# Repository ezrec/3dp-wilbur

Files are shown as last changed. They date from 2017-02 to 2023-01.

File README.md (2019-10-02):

# Wilbur - a Core-XY arm printer

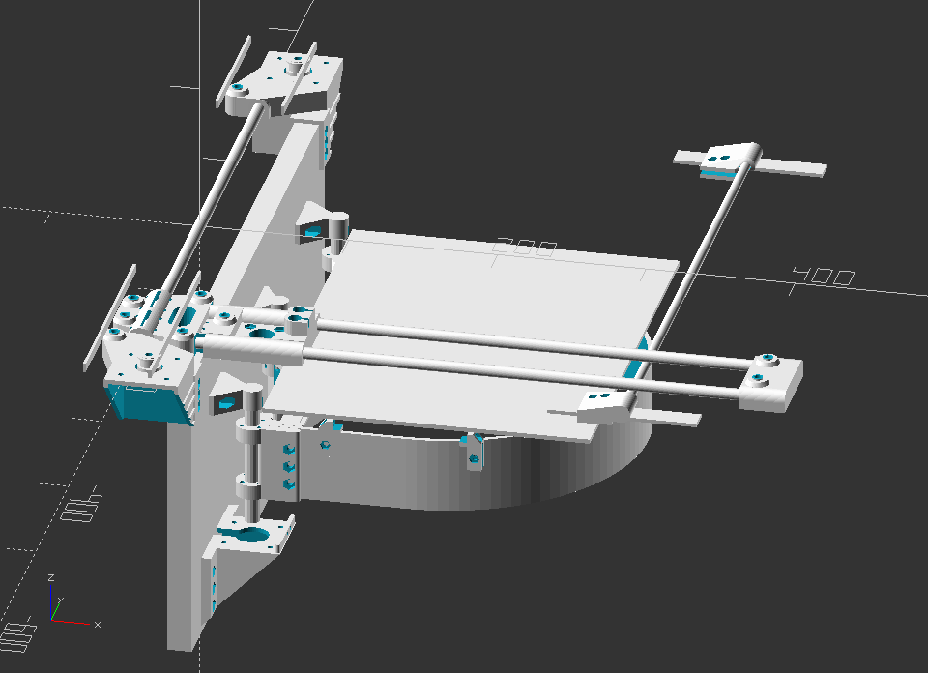
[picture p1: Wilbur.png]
Image of Wilbur


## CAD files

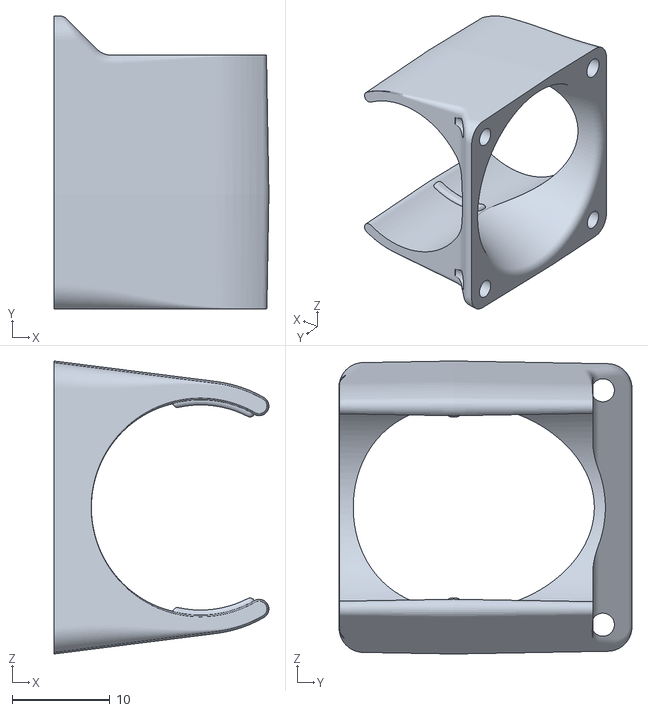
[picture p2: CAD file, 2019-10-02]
E3D/V6.6_Duct.stl
22.0 x 30.0 x 30.0

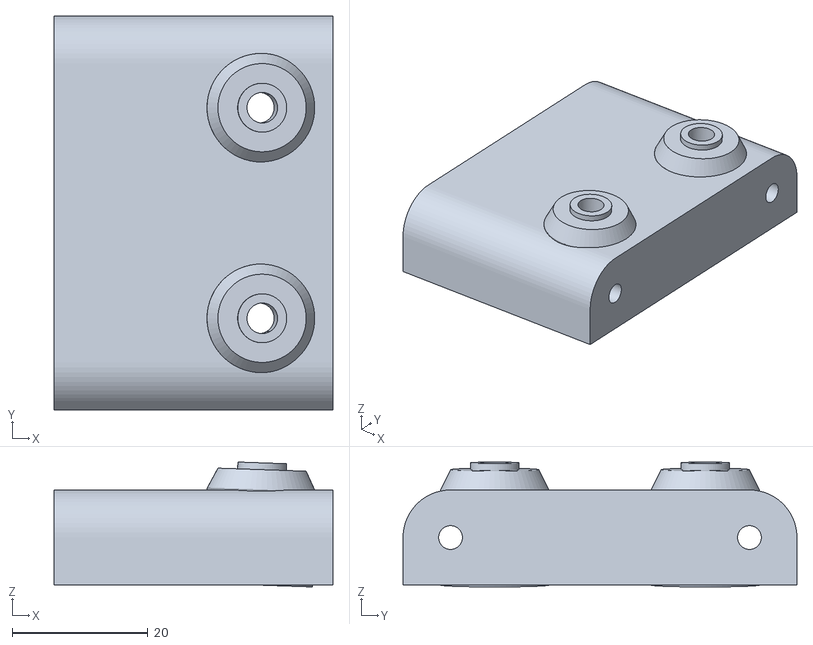
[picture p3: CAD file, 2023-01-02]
stl/wilbur_x_cap.stl
41.0 x 58.0 x 18.4

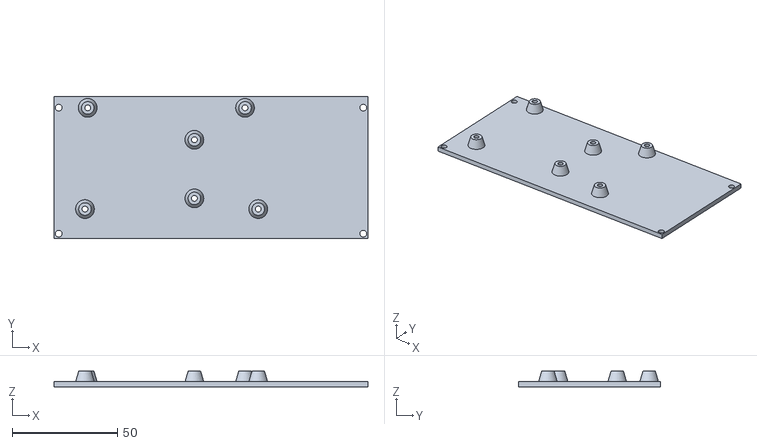
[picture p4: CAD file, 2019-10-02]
stl/wilbur_control_box_base.stl
149.5 x 67.5 x 7.50

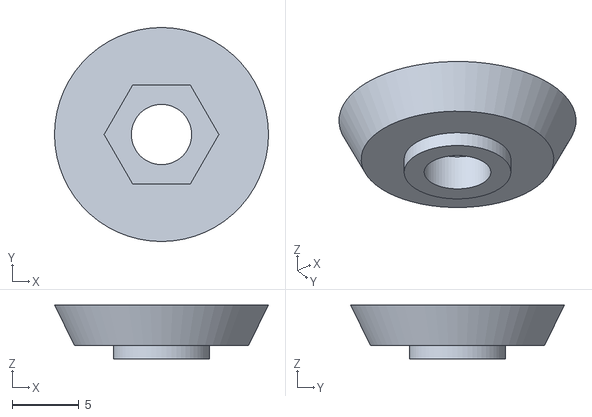
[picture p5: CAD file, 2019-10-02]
stl/wilbur_bearing_cap.stl
16.0 x 16.0 x 4.01

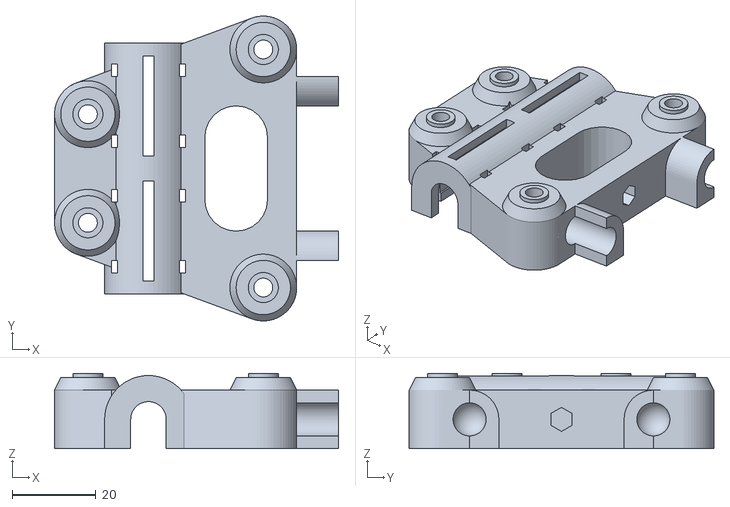
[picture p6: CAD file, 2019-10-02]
stl/wilbur_block.stl
68.0 x 73.0 x 18.0

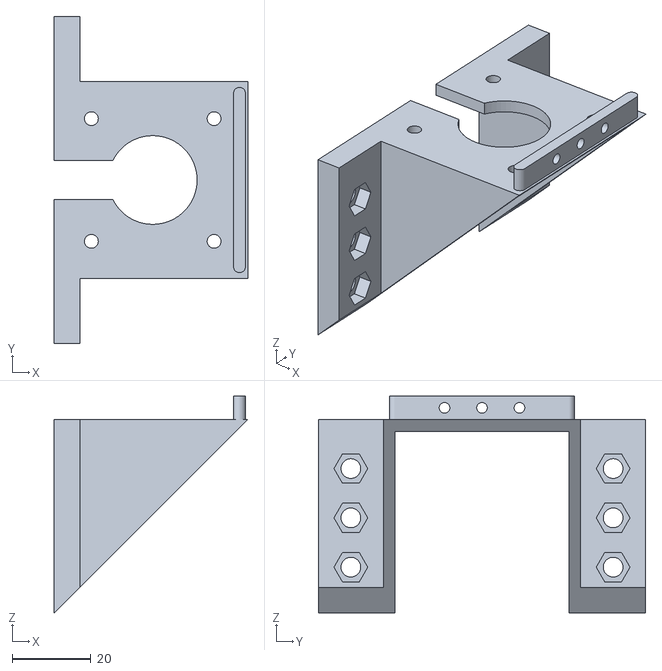
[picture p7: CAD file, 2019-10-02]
stl/wilbur_z_motor.stl
49.1 x 83.0 x 55.0

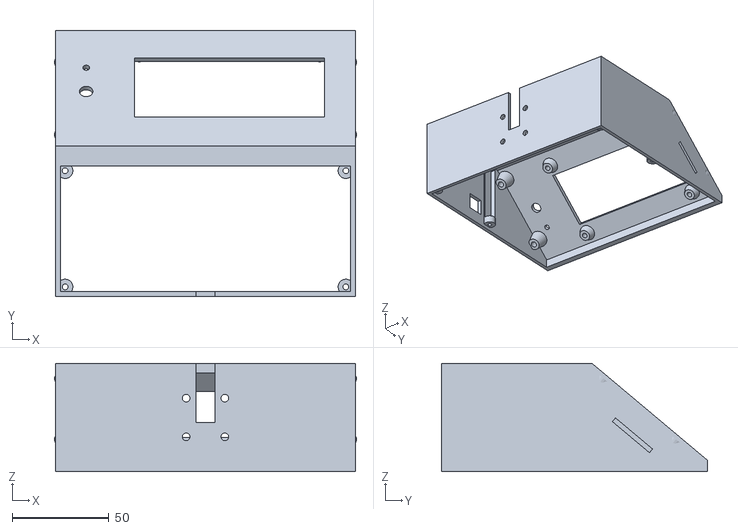
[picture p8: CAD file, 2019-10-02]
stl/wilbur_control_box.stl
156.0 x 137.5 x 56.0

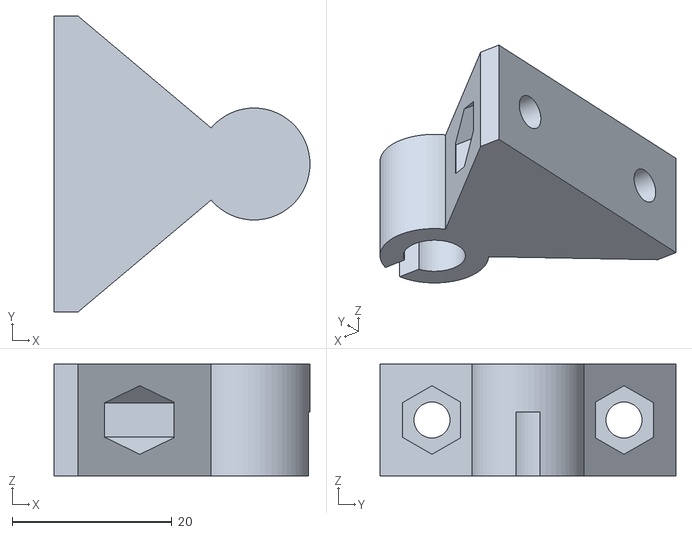
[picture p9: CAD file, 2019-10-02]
stl/wilbur_z_cap.stl
32.0 x 37.0 x 14.0

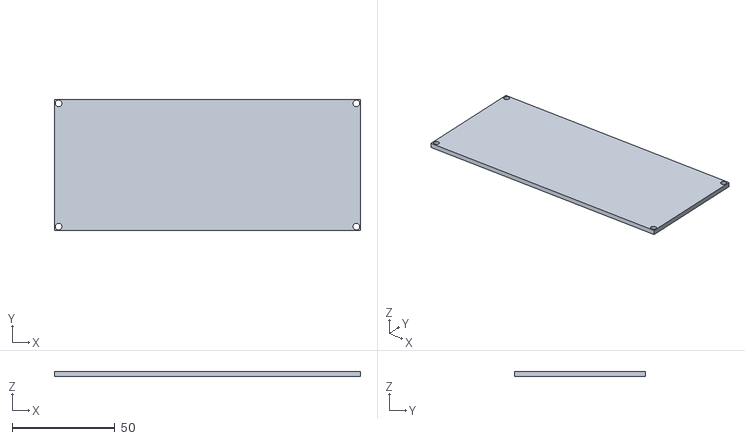
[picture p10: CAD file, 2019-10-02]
stl/wilbur_control_box_lid.stl
149.0 x 64.0 x 2.50

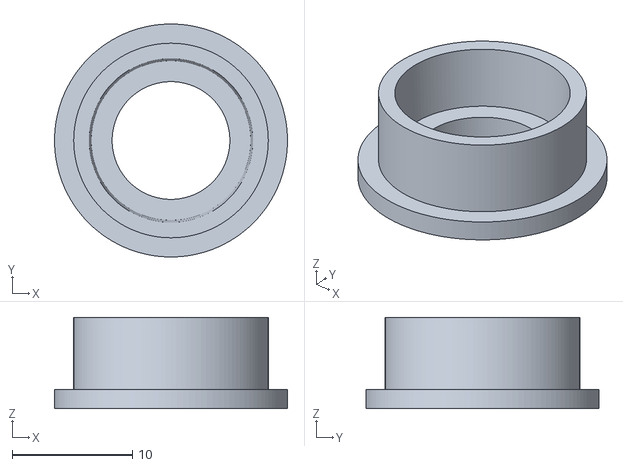
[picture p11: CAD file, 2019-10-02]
stl/wilbur_bearing_sleeve.stl
19.4 x 19.4 x 7.60

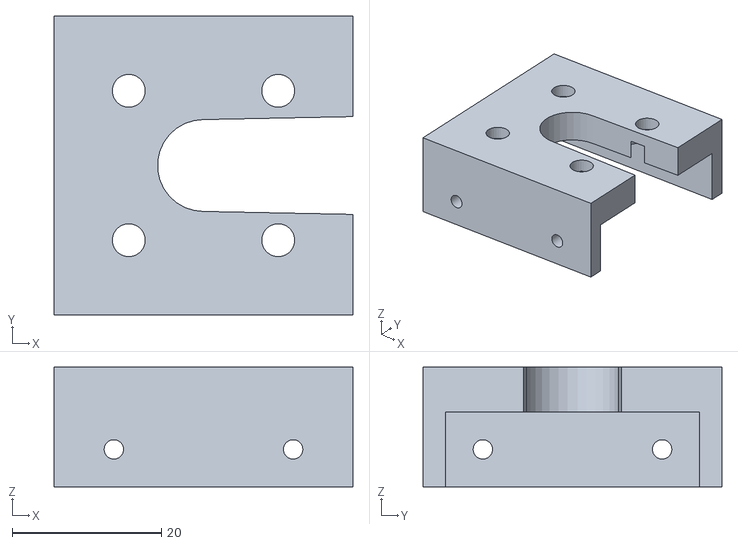
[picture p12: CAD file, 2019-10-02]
stl/wilbur_hotend_e3d_v6.stl
40.0 x 40.0 x 16.0

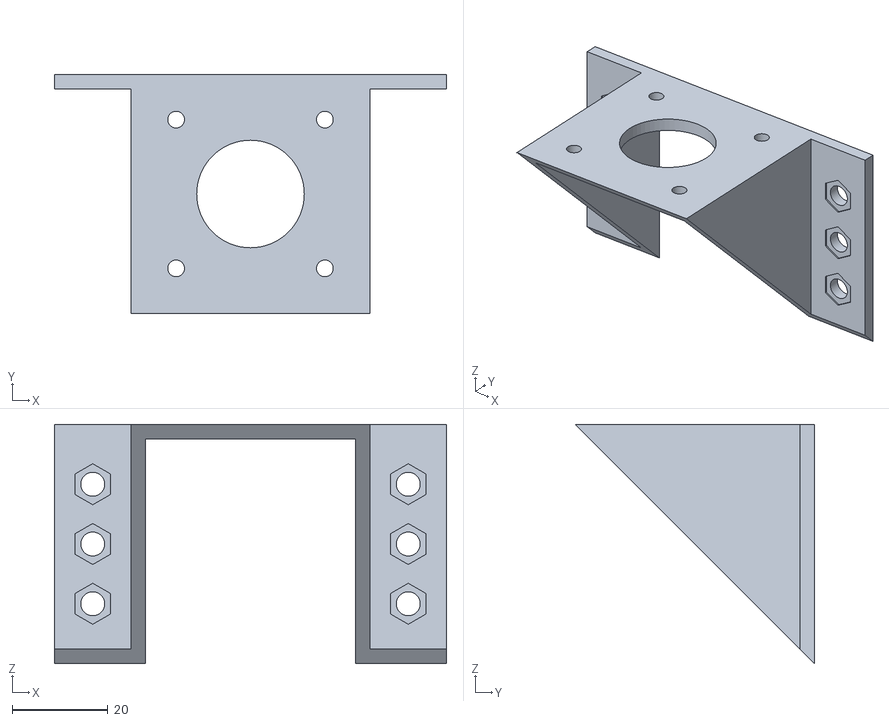
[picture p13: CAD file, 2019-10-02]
stl/wilbur_z_mount.stl
82.0 x 50.0 x 50.0

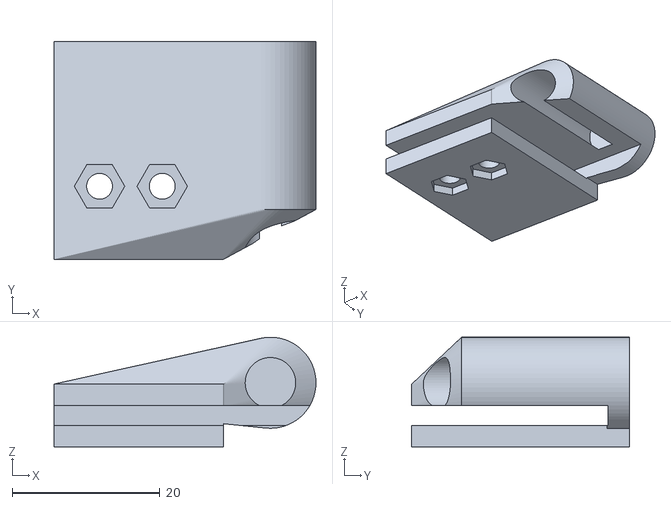
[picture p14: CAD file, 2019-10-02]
stl/wilbur_y_rail_min.stl
35.5 x 29.5 x 14.8

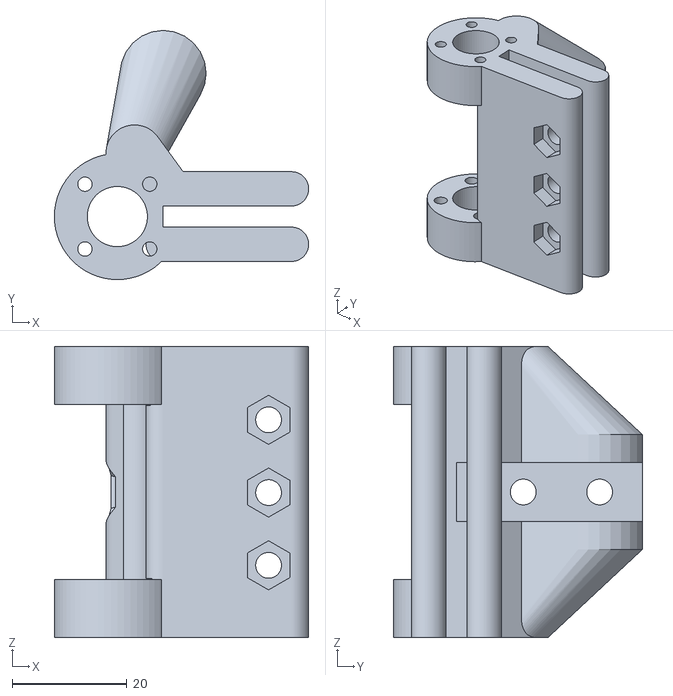
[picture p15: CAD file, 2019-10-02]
stl/wilbur_z_edge.stl
44.4 x 43.5 x 50.8

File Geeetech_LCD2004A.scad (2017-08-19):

bottom_plate=[150, 55, 1.6];

top_plate = [98.2, 60, 1.6];

fn=30;

function geeetech_lcd2004a_size() = [150, 63, 10];

module plate_drills(size=[10,20, 30], offset=2, drill=3)
{
    translate([offset, offset]) circle(d=drill, $fn=fn);
    translate([size[0]-offset, offset]) circle(d=drill, $fn=fn);
    translate([offset, size[1]-offset]) circle(d=drill, $fn=fn);
    translate([size[0]-offset, size[1]-offset]) circle(d=drill, $fn=fn);
}

module plate_mounts(size=[10,20, 30], offset=2, drill=3, height=10, wall=2)
{
    translate([0, 0, size[2]]) difference()
    {
        union()
        {
            translate([offset, offset])
                cylinder(d1=drill+wall*2, d2=drill+wall*4, h=height, $fn=fn);
            translate([size[0]-offset, offset])
                cylinder(d1=drill+wall*2, d2=drill+wall*4, h=height, $fn=fn);
            translate([offset, size[1]-offset])
                cylinder(d1=drill+wall*2, d2=drill+wall*4, h=height, $fn=fn);
            translate([size[0]-offset, size[1]-offset])
                cylinder(d1=drill+wall*2, d2=drill+wall*4, h=height, $fn=fn);
        }
        translate([0, 0, -0.1]) linear_extrude(height=height+0.2) plate_drills(size, offset, drill);
    }
}

module plate(size=[10,20, 30], offset=2, drill=3)
{
    linear_extrude(height=size[2]) difference()
    {
        square([size[0], size[1]]);
        plate_drills(size, offset, drill);
    }
}

module geeetech_lcd2004a()
{
    translate([-bottom_plate[0]/2, 0, 0])
    {
        plate(bottom_plate, offset=3, drill=4);
        // SD card
        translate([-10, 9, -2.4])
            cube([35, 25, 2.5]); 
        translate([0, 0, bottom_plate[2]]) {
            translate([bottom_plate[0]-16.5, 5.5, 0]) {
                cube([6.3, 6.3, 3.5]);
                translate([6.3/2, 6.3/2, 0]) {
                    cylinder(d=3.5, h=14.5, $fn=fn);
                    translate([0, 16, 0]) {
                        translate([0, 0, 6.8/2]) cube([12, 12, 6.8], center=true);
                        cylinder(d=7, h=26.5, $fn=fn);
                    }
                }
            }
        }
        
        // LCD2004A
        translate([13.5, bottom_plate[1] - top_plate[1] - 3, bottom_plate[2]+3]) {
            plate(top_plate, offset=2.5, drill=3.5);
            translate([0, 10, top_plate[2]])
                cube([top_plate[0], 40, 9.5]);
        }
        
    }
}

module geeetech_lcd2004a_mounts(wall=4)
{
    translate([-bottom_plate[0]/2, 0, 0])
    {
        plate_mounts(bottom_plate, offset=3, drill=4, height=3+top_plate[2]+9.5-wall);
        translate([13.5, bottom_plate[1] - top_plate[1] - 3, bottom_plate[2]+3])
        {
            plate_mounts(top_plate, offset=2.5, drill=3.5, height=9.5-wall);
        }
    }
}

module geeetech_lcd2004a_holder(angle=40, width=80, height=100, wall=3)
{
    old_size=geeetech_lcd2004a_size();
    size = [old_size[0], old_size[1] + 10, old_size[2]];
    h = height - sin(angle)*(size[1]+wall*2);

    translate([0, 0, h])
    {
        // Polyline
        difference()
        {
            translate([-size[0]/2-wall, 0, 0]) rotate([0, 0, 90]) rotate([90, 0, 0]) difference()
            {
                 linear_extrude(height=size[0]+wall*2) polygon([[0, 0], [0, -h], [width, -h], [width, sin(angle)*(size[1]+wall*2)], [cos(angle)*(size[1]+wall*2), sin(angle)*(size[1]+wall*2)]]);
                 translate([0, -0.01, wall]) linear_extrude(height=size[0]) polygon([[wall+cos(angle)*wall, 0], [wall+cos(angle)*wall, -h], [width-wall, -h], [width-wall,sin(angle)*size[1]], [cos(angle)*size[1]+wall+cos(angle)*wall, sin(angle)*size[1]]]);
            }

            translate([0, wall+wall*cos(angle)+size[2]+size[2]*cos(angle) - 0.5, 0]) rotate([angle, 0, 0])
                geeetech_lcd2004a();
        }

        translate([0, wall+wall*cos(angle)+size[2]+size[2]*cos(angle) - 0.5, 0]) rotate([angle, 0, 0])
        {
            geeetech_lcd2004a_mounts();
            % geeetech_lcd2004a();
        }
    }
}


geeetech_lcd2004a_holder(wall=3);

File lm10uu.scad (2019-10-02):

mm = 1.0;
in = 25.4;

fn = 120;

module bearing_surface(od = 10 * mm, id = 5 * mm, surfaces = 4)
{
    difference()
    {
        union()
        {
            // Outer wall
            difference()
            {
                circle(d = od, $fn=fn);
                circle(d = od - (od - id) * 1 / 3, $fn=fn);
            }

            // Surfaces
            for (a = [0:surfaces-1])
            {
                a1 = a * 360/surfaces;
                a2 = a1 + 360/surfaces/2;
                polygon([[0,0], [od/2 * cos(a1), od/2 * sin(a1)], [od/2 * cos(a2), od/2 * sin(a2)]]);
            }
        }
        
        circle(d = id, $fn = fn);
    }
}

module lm_bearing(h=10, id=5, od=10, surfaces=6)
{
    linear_extrude(height=h/2, twist = h)
    {
        bearing_surface(od=od, id=id * 0.975, surfaces = surfaces);
    }
    mirror([0, 0, 1]) linear_extrude(height=h/2, twist = h)
    {
        bearing_surface(od=od, id=id * 0.975, surfaces = surfaces);
    }
}

module lm8uu()
{
    lm_bearing(h=24*mm, od=15*mm, id=8*mm, surfaces=13);
}

module lm10uu()
{
    lm_bearing(h=29*mm, od=19*mm, id=10*mm, surfaces=15);
}

lm8uu();

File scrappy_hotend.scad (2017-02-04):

//
// Copyright (C) 2017, Jason S. McMullan <jason.mcmullan@gmail.com>
// All rights reserved.
//
// Licensed under the MIT License:
//
// Permission is hereby granted, free of charge, to any person obtaining
// a copy of this software and associated documentation files (the "Software"),
// to deal in the Software without restriction, including without limitation
// the rights to use, copy, modify, merge, publish, distribute, sublicense,
// and/or sell copies of the Software, and to permit persons to whom the
// Software is furnished to do so, subject to the following conditions:
//
// The above copyright notice and this permission notice shall be included
// in all copies or substantial portions of the Software.
//
// THE SOFTWARE IS PROVIDED "AS IS", WITHOUT WARRANTY OF ANY KIND, EXPRESS OR
// IMPLIED, INCLUDING BUT NOT LIMITED TO THE WARRANTIES OF MERCHANTABILITY,
// FITNESS FOR A PARTICULAR PURPOSE AND NONINFRINGEMENT. IN NO EVENT SHALL THE
// AUTHORS OR COPYRIGHT HOLDERS BE LIABLE FOR ANY CLAIM, DAMAGES OR OTHER
// LIABILITY, WHETHER IN AN ACTION OF CONTRACT, TORT OR OTHERWISE, ARISING
// FROM, OUT OF OR IN CONNECTION WITH THE SOFTWARE OR THE USE OR OTHER
// DEALINGS IN THE SOFTWARE.
//
// All units are in mm

use <Geeetech/jhead_peek.scad>
use <mini_height_sensor.scad>

geeetech_peek_clamp_diameter = 12;
geeetech_peek_clamp_height = 4.5;
geeetech_peek_bulk_diameter = 16;
geeetech_peek_bulk_length = 29;

geeetech_peek_nozzle_height = 16;

m4_nut_flat=7;
m4_nut_height=3.5;

drill_tolerance = 0.25;

blower_fan_mounting_radius = 49.5/2;
blower_fan_width = 19.5;
blower_fan_mounting_post_height = 7;
blower_fan_mounting_post_diameter = 6.5;
blower_fan_radius = 41/2;
blower_fan_airflow_radius = 29/2;
blower_out_height = 30.5;

wall = 3;

fn=30;

module drill(d=3, h=1, tolerance=drill_tolerance)
{
    translate([0, 0, -0.1]) cylinder(d=d + tolerance*2, h=h+0.2, $fn =fn);
}

module blower_fan_of(cut=false)
{
    if (!cut)
    {
        // Mounting posts
        translate([0, blower_fan_width/2 - blower_fan_mounting_post_height, blower_fan_radius])
        for (x=[0:2]) rotate([0, 45+x*90, 0]) translate([blower_fan_mounting_radius, 0, 0])
                rotate([-90, 0, 0]) cylinder(d=blower_fan_mounting_post_diameter, h=blower_fan_mounting_post_height, $fn=fn);
        
        // Mounting
        translate([-blower_fan_radius, blower_fan_width/2-0.1, 0])
            cube([blower_fan_radius*2, wall, blower_fan_radius*2]);
    }
    else
    {
        translate([0, -blower_fan_width/2, blower_fan_radius]) {
            rotate([-90, 0, 0]) cylinder(r=blower_fan_radius, h=blower_fan_width, $fn=fn);
            translate([0, 0, blower_fan_radius - blower_out_height])
                cube([blower_fan_radius, blower_fan_width, blower_out_height]);
        }
        
        // Mounting drills
        translate([0, blower_fan_width/2 - blower_fan_mounting_post_height, blower_fan_radius])
        for (x=[0:2]) rotate([0, 45+x*90, 0]) translate([blower_fan_mounting_radius, 0, 0])
                rotate([-90, 0, 0]) drill(d=3, h=blower_fan_mounting_post_height+100, $fn=fn);
        
        // Airflow
        translate([0, -blower_fan_width/2, blower_fan_radius])
            rotate([-90, 0, 0]) cylinder(r=blower_fan_airflow_radius, h=blower_fan_width+100+0.2, $fn=fn);
    }
}
            
module hotend_geeetech_peek_of(cut=false)
{
    if (!cut)
    {
        translate([0, 0, geeetech_peek_clamp_height/2]) cube([40, 40, geeetech_peek_clamp_height], center=true);
        hull()
        {
        translate([-20, 20-1, 0]) cube([40, 1,geeetech_peek_clamp_height ]);
        // Mounting
        translate([-blower_fan_radius - geeetech_peek_bulk_diameter/2 - wall, 0, -blower_fan_radius*2])
            translate([-blower_fan_radius, blower_fan_width/2-0.1, 0])
            cube([blower_fan_radius*2, 1, blower_fan_radius*2]);
        }
        
        // Extra mounting bracket
        translate([20-0.01, -20, -10]) cube([wall, 40, 10+geeetech_peek_clamp_height]);        
    }
    else
    {
        // Cylinder drill
        translate([0, 0, -geeetech_peek_bulk_length])
            drill(d=geeetech_peek_bulk_diameter, h=geeetech_peek_bulk_length);
        
        // Mounting slot
        translate([0, 0, -0.01]) linear_extrude(height=geeetech_peek_clamp_height+0.02) hull()
        {
            circle(d=geeetech_peek_clamp_diameter + drill_tolerance*2+0.1);
            translate([0, -100, 0])
                circle(d=geeetech_peek_clamp_diameter + drill_tolerance*2+0.1);
        }
        
        // M4 mounting holes, 20mm apart
        for (r = [0:90:270]) rotate([0, 0, 45+r]) translate([20*sin(45), 0, 0]) {
            drill(h=geeetech_peek_clamp_height, d=4);
            translate([0, 0, -20])
                rotate([0, 0, 45+r]) cylinder(r=m4_nut_flat/sqrt(3)+drill_tolerance, h=m4_nut_height/2+20+0.1, $fn=6);
        }
        
        // Extra mounting bracket drills
        translate([20-0.01, 0, -5]) {
            translate([0, -10, 0]) rotate([0, 90, 0]) drill(h=5, d=3);
            translate([0, 10, 0]) rotate([0, 90, 0]) drill(h=5, d=3);
        }
    }
              
    translate([-blower_fan_radius - geeetech_peek_bulk_diameter/2 - wall, 0, -blower_fan_radius*2])
        blower_fan_of(cut);
 }

module scrappy_hotend_geeetech_peek()
{
    difference()
    {
        hotend_geeetech_peek_of(cut=false);
        hotend_geeetech_peek_of(cut=true);
    }
}

module scrappy_height_sensor_mount()
{
    height=geeetech_peek_bulk_length+geeetech_peek_nozzle_height-7;
    translate([20, 0, -height]) {
        difference()
        {
            translate([-5, -20+5, 0])
                cube([5, 30, height]);
            translate([-5, 0, (geeetech_peek_nozzle_height-6)/2])
                scale([8, 25, (height - geeetech_peek_nozzle_height+6)*3]) sphere(r=0.5, $fn=fn);
            # translate([-5.01, 0, height-5]) {
                translate([0, -10, 0]) rotate([0, 90, 0]) drill(h=5, d=3-drill_tolerance*2);
                translate([0, 10, 0]) rotate([0, 90, 0]) drill(h=5, d=3-drill_tolerance*2);
            }
        }
        
        translate([-5, 0, 0]) difference()
        {
            rotate([90, 0, 0]) rotate_extrude(angle=30, convexity=2) {
                difference() {
                    translate([0, -20+5]) square([5, 30]);
                    scale([8, 25]) circle(r=0.5, $fn=fn);
                }
            }
            translate([-5.1, -20.1+5, 0]) cube([10.2, 30.2, 5.1]);
            translate([-5.1, -20.1+5, -5.1]) cube([5.1, 30.2, 5.1]);
        }
        
        translate([0, 0, -5]) rotate([0, 0, 90]) mini_height_sensor_mount();
    }
}

scrappy_hotend_geeetech_peek();
scrappy_height_sensor_mount();
% geeetech_jhead_peek();
// vim: set shiftwidth=4 expandtab: //

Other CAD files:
stl/wilbur_fan_e3d_v6.stl
stl/wilbur_z_foot.stl
stl/wilbur_y_motor_min.stl
stl/wilbur_power_box.stl
wilbur.scad
E3D/chimera.scad
E3D/utility.scad
E3D/v6_block.scad
E3D/v6_break.scad
E3D/v6_lite.scad
E3D/v6_nozzle.scad
mini_height_sensor.scad
stl/wilbur_sensor_e3d_v6.stl
stl/wilbur_sled.stl
stl/wilbur_y_motor_max.stl
stl/wilbur_y_rail_max.stl
stl/wilbur_z_center.stl
wilbur_hotend_e3d.scad
wilbur_power_box.scad

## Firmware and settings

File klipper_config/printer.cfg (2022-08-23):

# Arduino aliases for atmega2560/1280 (Arduino mega) boards
[board_pins arduino-mega]
aliases:
    ar0=PE0, ar1=PE1, ar2=PE4, ar3=PE5, ar4=PG5,
    ar5=PE3, ar6=PH3, ar7=PH4, ar8=PH5, ar9=PH6,
    ar10=PB4, ar11=PB5, ar12=PB6, ar13=PB7, ar14=PJ1,
    ar15=PJ0, ar16=PH1, ar17=PH0, ar18=PD3, ar19=PD2,
    ar20=PD1, ar21=PD0, ar22=PA0, ar23=PA1, ar24=PA2,
    ar25=PA3, ar26=PA4, ar27=PA5, ar28=PA6, ar29=PA7,
    ar30=PC7, ar31=PC6, ar32=PC5, ar33=PC4, ar34=PC3,
    ar35=PC2, ar36=PC1, ar37=PC0, ar38=PD7, ar39=PG2,
    ar40=PG1, ar41=PG0, ar42=PL7, ar43=PL6, ar44=PL5,
    ar45=PL4, ar46=PL3, ar47=PL2, ar48=PL1, ar49=PL0,
    ar50=PB3, ar51=PB2, ar52=PB1, ar53=PB0, ar54=PF0,
    ar55=PF1, ar56=PF2, ar57=PF3, ar58=PF4, ar59=PF5,
    ar60=PF6, ar61=PF7, ar62=PK0, ar63=PK1, ar64=PK2,
    ar65=PK3, ar66=PK4, ar67=PK5, ar68=PK6, ar69=PK7,
    analog0=PF0, analog1=PF1, analog2=PF2, analog3=PF3, analog4=PF4,
    analog5=PF5, analog6=PF6, analog7=PF7, analog8=PK0, analog9=PK1,
    analog10=PK2, analog11=PK3, analog12=PK4, analog13=PK5, analog14=PK6,
    analog15=PK7,
    # Marlin adds these additional aliases
    ml70=PG4, ml71=PG3, ml72=PJ2, ml73=PJ3, ml74=PJ7,
    ml75=PJ4, ml76=PJ5, ml77=PJ6, ml78=PE2, ml79=PE6,
    ml80=PE7, ml81=PD4, ml82=PD5, ml83=PD6, ml84=PH2,
    ml85=PH7

# Filament sensor
[filament_switch_sensor ext1_out]
pause_on_runout: True
switch_pin: ^!ar15

# Enable pause/resume
[pause_resume]
recover_velocity: 50

# Virtual SD Card
#[virtual_sdcard]
#path=/opt/octoprint/wilbur/uploads/

[output_pin ATX_POWER]
pin: !ar2
value: 0

# ATX Power On
[gcode_macro M80]
gcode: SET_PIN PIN=ATX_POWER VALUE=1

# ATX Power off
[gcode_macro M81]
gcode: SET_PIN PIN=ATX_POWER VALUE=0

# Define a probe
[probe]
pin: ar18
x_offset: 0.0
y_offset: -32.0
z_offset = 3.4

[bed_tilt]
# Sigh. We have to manually compensate for the probe offset
points: 40,40
  150,40
  150,260
  40,260

[stepper_x]
step_pin: ar54
dir_pin: ar55
enable_pin: !ar38
rotation_distance: 32
microsteps: 16
position_endstop: -9
endstop_pin: ^!ar3
#endstop_pin: ^ar2
homing_speed: 50
position_min: -9
position_max: 180

[stepper_y]
step_pin: ar60
dir_pin: !ar61
enable_pin: !ar56
rotation_distance: 32
microsteps: 16
endstop_pin: ^!ar14
#endstop_pin: ^ar15
position_endstop: -12
position_min: -12
position_max: 270
homing_speed: 50

[stepper_z]
step_pin: ar46
dir_pin: ar48
enable_pin: !ar62
rotation_distance: 4
microsteps: 16
#endstop_pin: ^ar18
#endstop_pin: ^!ar19
endstop_pin: probe:z_virtual_endstop
position_min: -10
position_max: 250

[safe_z_home]
home_xy_position: 10,50
move_to_previous: True
z_hop: 5.0

[extruder]
step_pin: ar26
dir_pin: ar28
enable_pin: !ar24
rotation_distance: 32
microsteps: 16
nozzle_diameter: 0.600
filament_diameter: 1.750
heater_pin: ar10
sensor_type: ATC Semitec 104GT-2
sensor_pin: analog13
#control: pid
#pid_Kp: 22.2
#pid_Ki: 1.08
#pid_Kd: 114
min_temp: 0
max_temp: 230
pressure_advance: 0.1

[heater_bed]
heater_pin: ar8
sensor_type: NTC 100K beta 3950
sensor_pin: analog15
#control: watermark
min_temp: 0
max_temp: 130

[fan]
pin: ar9

[mcu]
serial: /dev/ttyACM0
baud: 230400

[printer]
kinematics: corexy
max_velocity: 300
max_accel: 3000
max_z_velocity: 5
max_z_accel: 100

# Common EXP1 / EXP2 (display) pins
[board_pins]
aliases:
    # Common EXP1 header found on many "all-in-one" ramps clones
    EXP1_1=ar37, EXP1_3=ar17, EXP1_5=ar23, EXP1_7=ar27, EXP1_9=<GND>,
    EXP1_2=ar35, EXP1_4=ar16, EXP1_6=ar25, EXP1_8=ar29, EXP1_10=<5V>,
    # EXP2 header
    EXP2_1=ar50, EXP2_3=ar31, EXP2_5=ar33, EXP2_7=ar49, EXP2_9=<GND>,
    EXP2_2=ar52, EXP2_4=ar53, EXP2_6=ar51, EXP2_8=ar41, EXP2_10=<RST>
    # Pins EXP2_1, EXP2_6, EXP2_2 are also MISO, MOSI, SCK of bus "spi"
    # Note, some boards wire: EXP2_8=<RST>, EXP2_10=ar41

######################################################################
# "RepRapDiscount 2004 Smart Controller" type displays
######################################################################

[display]
lcd_type: hd44780
rs_pin: EXP1_4
e_pin: EXP1_3
d4_pin: EXP1_5
d5_pin: EXP1_6
d6_pin: EXP1_7
d7_pin: EXP1_8
encoder_pins: ^!EXP2_3, ^!EXP2_5
click_pin: ^!EXP1_2
#kill_pin: ^!EXP2_8

[output_pin beeper]
pin: EXP1_1

[include mainsail.cfg]

[include client_macros.cfg]

[include timelapse.cfg]

#*# <---------------------- SAVE_CONFIG ---------------------->
#*# DO NOT EDIT THIS BLOCK OR BELOW. The contents are auto-generated.
#*#
#*# [bed_tilt]
#*# x_adjust = -0.035733
#*# y_adjust = 0.004224
#*# z_adjust = 0.533348
#*#
#*# [extruder]
#*# control = pid
#*# pid_kp = 33.441
#*# pid_ki = 2.008
#*# pid_kd = 139.198
#*#
#*# [heater_bed]
#*# control = pid
#*# pid_kp = 66.295
#*# pid_ki = 0.976
#*# pid_kd = 1126.183

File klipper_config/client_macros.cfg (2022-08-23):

# This file contains common pin mappings for RAMPS (v1.3 and later)
# boards. RAMPS boards typically use a firmware compiled for the AVR
# atmega2560 (though other AVR chips are also possible).

[gcode_macro PRINT_START]
gcode: M80 # Turn on ATX power supply
    G28 X0 Y0 # Home only X and Y
    G1 X0 Y-5 # Move to 'ooze zone'
    M190 S{ params.BED|int } # Heat bed up to 50C
    M104 T0 S{ params.TEMP0|int }  # Heat extruder up to 190C
    M109 T0 S{ params.TEMP0|int }  # Wait for heater to power up
    G28 Z0 # Home Z
    G1 X0 Y-5 # Move to 'ooze zone'

[gcode_macro PRINT_END]
gcode: M107 # Turn off fan
    M190 S0 # Turn off bed
    M104 T0 S0 # Turn off extruder
    G28 X0 Y0 # Home to start position
    M84 # Turn off steppers
    M81 # Turn off machine

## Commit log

2017-01-16 Complete initial CoreXY linear motion
    [scrappy.scad]
2017-01-17 - Add Makefile - Iteratite design
    [scrappy.scad]
2017-01-18 Switch to a more classic H-Bot style arrangement
    [scrappy.scad]
2017-01-19 Lots of updates, primarily to increase buildable area
    [scrappy.scad]
2017-01-20 - Convert back to dual rail - Use 6.2mm rod for resting Y axis
    [scrappy.scad]
2017-01-28 - Increase rod wall size - Other stuff
    [scrappy.scad, scrappy_z_bracket.scad, scrappy_z_clip.scad]
2017-01-31 Add Z bracket pieces
    [scrappy_z_bracket.scad, scrappy_z_clip.scad]
2017-02-01 Add power box and the Z endstop clip
    [scrappy_power_box.scad, scrappy_z_clip.scad]
2017-02-03 - Add hotend mount
    [scrappy_hotend.scad]
2017-02-04 - Add mini height sensor mount
    [mini_height_sensor.scad, scrappy_hotend.scad, scrappy_z_bracket.scad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]
2017-02-09 - Rework the peek bracket - Rework the glass Z holder (add justment screws)
    [scrappy.scad, scrappy_hotend_e3d.scad, scrappy_hotend_geeetech.scad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]
2017-02-14 Power box and end rail updates
    [Geeetech_LCD2004A.scad, scrappy.scad, scrappy_power_box.scad]
2017-08-19 Final revision for scanner-based Z stage
    [Geeetech_LCD2004A.scad, scrappy_hotend_e3d.scad, scrappy_power_box.scad]
2018-01-02 - Use new units (in and mm) explictly
    [scrappy.scad]
2018-01-02 - Move Y rails in to prevent MDF collision with Z sled
    [scrappy.scad]
2018-01-08 - Add new Z axis parts
    [scrappy.scad, scrappy_z_bracket.scad, scrappy_z_clip.scad]
2018-01-08 WIP: E3D volcano changes
    [scrappy_hotend_e3d.scad]
2019-10-02 Change the name from 'Scrappy' to 'Wilbur'
    [V6.6_Duct.stl, chimera.scad, lm10uu.scad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]
2019-10-02 Add pre-rendered STL
    [wilbur_bearing_cap.stl, wilbur_bearing_sleeve.stl, wilbur_block.stl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]
2022-08-23 Initial Klipper config
    [client_macros.cfg, printer.cfg]
2023-01-02 minor tolarance changes
    [wilbur.scad, wilbur_x_cap.stl]
